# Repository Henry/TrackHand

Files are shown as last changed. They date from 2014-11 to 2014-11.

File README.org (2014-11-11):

#+TITLE: *DataHand DH200-6 with USB Micro-controller and Laser Trackball*
#+AUTHOR: nil
#+EMAIL: no-reply
#+OPTIONS: author:nil email:nil ^:{}
#+LaTeX_HEADER: \usepackage[parfill]{parskip}
#+STARTUP: hidestars odd

* Aim
  The initial aim of this project is to replace the archaic firmware in a
  DataHand DH200-6 keyboard with an ARM-based micro-controller and USB interface
  and use this as a test-platform for an integrated laser trackball using the
  ADNS-9800 LaserStream gaming sensor fitted closely below the finger cluster.
  The trackball is intended for finger control with the mouse buttons included
  in a special mode and mapped to the thumb-cluster keys.  The proposed layout
  of ball and switches is reminiscent of the excellent but obsolete Logitech
  TrackMan Marble FX trackball which I used for 15years:
  [[http://www.youtube.com/watch?v=k_sZMnmEOp4][Logitech TrackMan video]].

  Once the initial aim is fulfilled the trackball hardware and software could be
  fitted to the
  [[http://geekhack.org/index.php?topic=41422.msg827691#msg827691][DodoHand]] as
  an alternative to the proposed TrackPoint pointing device.  Details of this
  project may be found in the same thread:
  [[http://geekhack.org/index.php?topic=41422.msg1509793#msg1509793][TrackHand]]
  with some discussion concerning the suitability of the 2 1/4" trackball for
  the DodoHand.
* Images
  Here are the upgraded units with a trackball in the right-hand unit only,
  mouse buttons mapped to the right-hand thumb-cluster in function mode and
  current legends:
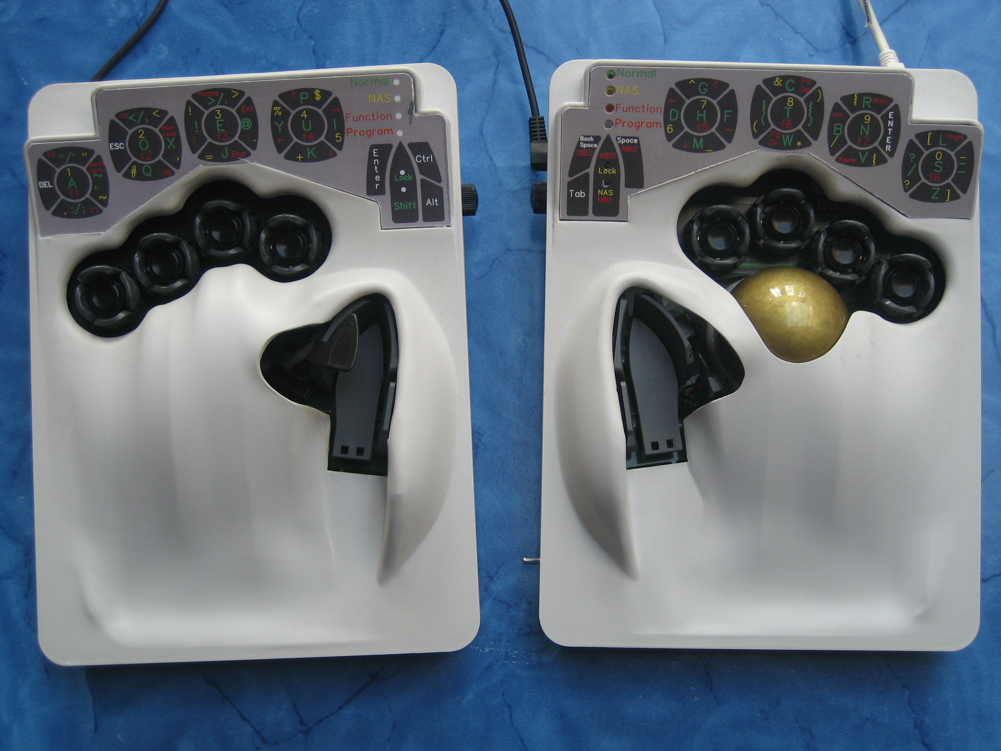
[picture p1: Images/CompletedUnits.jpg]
  
  Here is the inside of the right-hand unit showing the new micro-controller and
  trackball with the ADNS-9800 sensor:
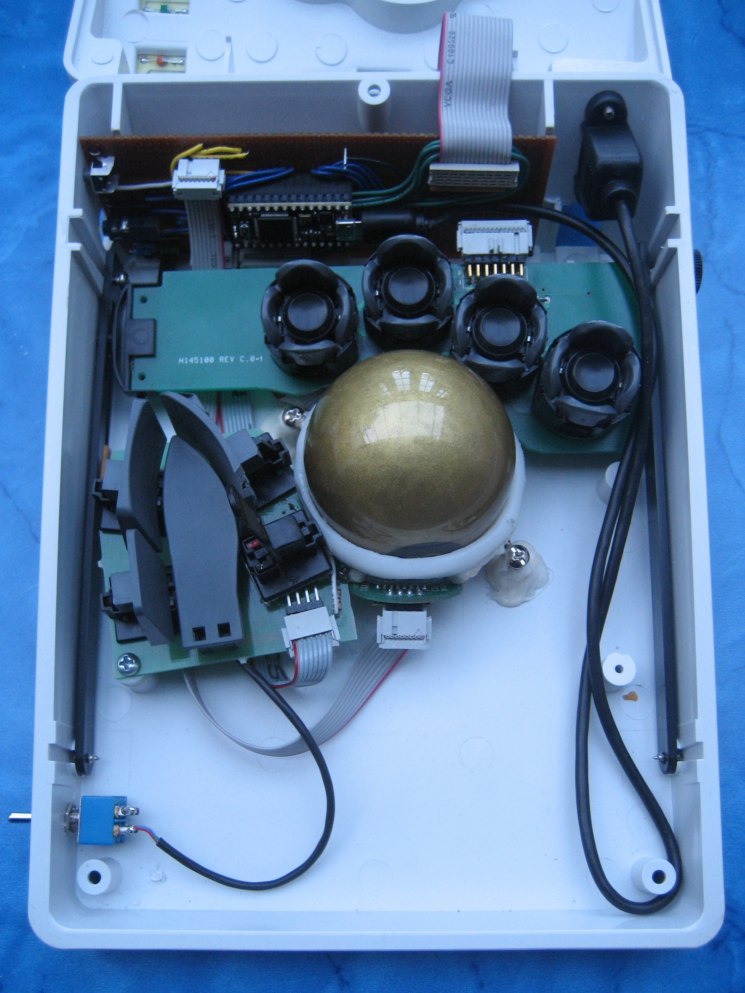
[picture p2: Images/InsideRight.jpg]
  
* Teensy 3 Software
  The [[https://www.pjrc.com/teensy/teensy31.html][Teensy-3.1]] micro-controller
  is used in this project.  Any of the Teensy
  boards could be used but I wanted to play around with this latest and most
  powerful offering from PJRC and the price is very reasonable.  The
  installation notes are really for my own reference but they may be useful to
  others.  I am developing software under OpenSuSE but all these tools are
  available for other GNU/Linux distributions.
*** Install AVR tools on OpenSuSE
    Open /firefox/ and follow instructions on
    + http://software.opensuse.org/package/cross-avr-gcc
    + Use the 1-click install of /CrossToolchain:avr/
    Or add the repository and use =zypper=
    + sudo zypper addrepo http://download.opensuse.org/repositories/CrossToolchain:/avr/openSUSE_13.1/
    + =zypper in cross-avr-gcc avr-libc cross-avr-binutils=
*** Enable serial (based on notes from PJRC)
    The udev rule file gives non-root users permission to use the Teensy device.
    Download [[http://www.pjrc.com/teensy/49-teensy.rules][49-teensy.rules]]
    + =sudo cp 49-teensy.rules /etc/udev/rules.d/=
    Add user to /uucp/ and /dialout/ groups
    + =uucp:x:14:<username>=
    + =dialout:x:16:<username>=
*** Avoid Teensyduino
    Teensyduino is the annoying Java interface to building and loading teensy
    applications.  This is the only method supported directly by PJRC on the
    Teensy-3.1.  However, other people are maintaining CLI support software for
    the Teensy-3.1 based on the applications released by PJRC for the Teensy-2.
*** Make (used instead of Teensyduino)
    Install the arduino libraries and make file for Teensy-3.x
    + =git clone= https://github.com/apmorton/teensy-template
    This repository started from the /teensy-template/ repository, so you do not
    need this step unless you want to write code for another project.

    To test simply
    + =make=
    + =make upload=
    + Press the button
*** CLI Loader (used instead of Teensyduino)
    Download the latest CLI app for teensy-3.1
    + =git clone= https://github.com/texane/teensy3.git
    + =cd teensy3/src/teensy_loader_cli=
    + =make=
    + Install somewhere in your =PATH= /eg/: =cp teensy_loader_cli ~/bin/linux=
*** Using GNU screen or cat to listen to serial messages
    On OpenSuSE the USB serial device =/dev/ttyACM0= is created following
    =Serial.begin()= and may be interrogated using =screen= or just plain old
    =cat=:
    + =screen /dev/ttyACM0=
    + =cat /dev/ttyACM0=
    Sometimes there is a problem with the connection and printing stops due to
    buffering.  To remedy this change the tty settings:
    + stty -F /dev/ttyACM0 9600 raw
*** I2C comms library
    This library is included: /libraries/i2c_t3/
    + http://forum.pjrc.com/threads/21680-New-I2C-library-for-Teensy3
    I2C is used to connect the right-hand unit to the left-hand MCP23018
    IO-expander.
***** Teensy-3 pins
      + SCL: pin 19 with 4k7 pull-up resistor
      + SDA: pin 18 with 4k7 pull-up resistor
      To connect two teensys connect SCL to SCL and SDA to SDA with the pull-up
      resistors.
*** Serial Peripheral Interface (SPI) library
    This library is included: /libraries/spi4teensy3/
    + https://github.com/xxxajk/spi4teensy3
*** Low-power library
    This is included: /libraries/LowPower_Teensy3/
    + [[https://github.com/duff2013/LowPower_Teensy3.git]]
*** MCP23018 library
    Interface to the MCP23018 IO-expander used to scan the optical switch matrix
    in the left-hand unit and send the data to the Teensy-3.1 micro-controller
    in the right-hand unit via the I2C connection.  This library is an
    incomplete but sufficient interface to the MCP23018 chip created for this
    project with reference to the
    [[http://ww1.microchip.com/downloads/en/DeviceDoc/22103a.pdf][MP23018
    datasheet]].
*** ADNS-9800 LaserStream Gaming Sensor library
    The ADNS-9800 LaserStream Gaming Sensor is used to scan the motion ball.
    The Kicklighter breakout board is used
    + https://www.kickstarter.com/projects/1034145369/high-speed-laser-optical-sensor
    + https://www.tindie.com/products/jkicklighter/adns-9800-optical-laser-sensor/

    Teensy interface for the ADNS-9800 used in this project is based on that
    provided by John Kicklighter and connects to the Teensy-3.1 via the SPI
    + https://github.com/mrjohnk/ADNS-9800.git
    + https://github.com/mrjohnk/Trackball2.git
    with updates for the Teensy-3.1 from
    + https://github.com/pepijndevos/Dwergmuis
    and is included: /libraries/TrackBall/
* The DataHand DH200-6
  The DataHand keyboard receiving this extreme makeover is a second-hand 1993
  DH200-6 is decent condition and basically working.  All the existing
  electronics are removed leaving just the thumb and finger switch clusters.
  The leds on the key map panel are also be reused.
*** Thumb Cluster
    The 8-pin IDC header on thumb-cluster has the following connections and
    proposed Teensy-3.1 pin allocation
    | Pin | Line           | Switches | Connections               | Teensy pin |
    |-----+----------------+----------+---------------------------+------------|
    |   1 | Vcc            |          |                           |            |
    |   2 | XD0 (column 0) | 1 3 5    |                           |         14 |
    |   3 | Row 0          | 1 2      | ->D1k->(D1)->D2k->R1->Vcc |          5 |
    |   4 | XD1 (column 1) | 2 4 6    |                           |         15 |
    |   5 | Row 1          | 3 4      | ->D3k->(D3)->D4k->R1->Vcc |          6 |
    |   6 | Row 2          | 6        | ->D3k->R1->Vcc            |          8 |
    |   7 | Row 3          | 5        | ->D5k->R1->Vcc            |          7 |
    |   8 | GND            | 1-6      |                           |            |
    + Connect 1 to Vcc
    + Connect 8 to GND
    + Connect columns 0 and 1 to INPUT pins each with a 4k7 pull-up to Vcc.
    + Set rows 0-3 to HIGH
    + Scan rows by setting each to LOW in turn
    + Read state of each column, LOW is on.
*** Finger Cluster
    The 14-pin IDC header on finger-cluster has the following connections and
    proposed Teensy-3.1 pin allocation
    | Pin | Line           |                               Teensy pin |
    |-----+----------------+------------------------------------------|
    |   1 | Vcc            |                                          |
    |   2 | XD0 (column 0) |                                       14 |
    |   3 | Row 4          |                                        1 |
    |   4 | XD1 (column 1) | 15 (now 16 but should be put back to 15) |
    |   5 | Row 5          |                                        0 |
    |   6 | Row 6          | 16 (now 15 but should be put back to 16) |
    |   7 | Row 7          |                                        3 |
    |   8 | Row 8          |                                       17 |
    |   9 | Row 9          |                                        2 |
    |  10 | Row 10         |                                       20 |
    |  11 | Row 11         |                                       23 |
    |  12 | Row 12         |                                       21 |
    |  13 | Row 13         |                                       22 |
    |  14 | GND            |                                          |
    |     |                |                                          |
    + Connect 1 to Vcc
    + Connect 14 to GND
    + Connect columns 0 and 1 to INPUT pins each with a 4k7 pull-up to Vcc.
      (NOTE: columns 0 and 1 are the same for finger and thumb clusters)
    + Set rows 4-14 to HIGH
    + Scan rows by setting each to LOW in turn
    + Read state of each column, LOW is on.
***** Thumb and Finger Switch Indices
      The following tables provide the column, row and combined indices for each
      of the thumb and finger switches:
      | Thumb Switch | Column/Row/index |
      |--------------+------------------|
      | Knuckle      | 0 0 0            |
      | Nail         | 1 0 1            |
      | Down         | 0 1 2            |
      | DOWN         | 1 1 3            |
      | Pad          | 0 3 6            |
      | Up           | 1 2 5            |

      | Finger | Down    | North   | South   | East    | West    |
      |--------+---------+---------+---------+---------+---------|
      |      1 | 0 5  10 | 1 4  9  | 0 7  14 | 1 5  11 | 0 4  8  |
      |      2 | 0 11 22 | 1 9  19 | 1 7  15 | 1 11 23 | 0 9  18 |
      |      3 | 0 12 24 | 1 13 27 | 0 10 20 | 1 12 25 | 0 13 26 |
      |      4 | 0 6  12 | 1 8  17 | 1 10 21 | 1 6  13 | 0 8  16 |
*** Trackball
    The ADNS-9800 LaserStream Gaming Sensor Kicklighter breakout board connects
    to the Teensy 3 on the SPI interface using 4 pins + 1 pin for interupt:
    | Pin | ADNS | Teensy | Description     | Teensy pin |
    |-----+------+--------+-----------------+------------|
    |   1 | MI   | MISO   | Data input      |         12 |
    |   2 | VI   | Vcc    | 3.3V            |            |
    |   3 | SC   | SCK    | Clock           |         13 |
    |   4 | AG   | GND    | Ground          |            |
    |   5 | MO   | MOSI   | Data output     |         11 |
    |   6 | DG   | GND    | Ground          |            |
    |   7 | SS   | SS     | Select device   |         10 |
    |   8 | MOT  | --     | Motion interupt |         9  |
*** LEDs
    The LEDs on the key map panel on the DataHand case are reused with the
    following pin allocation on the Teensy-3.1:
    | LED               | Teensy pin |
    |-------------------+------------|
    | Shift             |         24 |
    | Caps Lock         |         25 |
    | --                |         26 |
    | --                |         27 |
    | Cursor/mouse mode |         28 |
    | Function mode     |         29 |
    | NAS mode          |         30 |
    | Normal mode       |         31 |
    | --                |         32 |
    | --                |         33 |
    + Note: LOW is on
*** Teensy-3 pin allocation
    Pin requirements:
    | Purpose                               | #pins |
    |---------------------------------------+-------|
    | I2C (comms between teensys)           |     2 |
    | SPI (comms with trackball) + interupt |     5 |
    | Key matrix column inputs              |     2 |
    | Thumb row outputs                     |     4 |
    | Finger row outputs                    |    10 |
    | Mode and modifier indicator LEDs      |     6 |
    | Wake-up GPIO pin                      |     1 |
    |---------------------------------------+-------|
    | Total                                 |    30 |
* Trackball Installation
  To provide the best shape for the finger-driven trackball fitted is the curve
  of the finger-cluster I found that the standard 2 1/4" pool-ball to be the
  best compromise.  From a curvature point of view a slightly larger ball might
  be more comfortable but then it would need a higher case and would require
  further re-arrangement of the thumb switches.  Also the 2 1/4" pool-ball is
  the largest high-quality ball readily available.  Even with this size of ball
  a significant change needed to be made to the thumb-cluster to fit it in a
  suitable position, starting with the relocation of the "up" switch further in
  to allow aggressive trimming of the PCB and re-routing of cut tracks.  Slight
  trimming of the finger-cluster PCB was also required but this did not require
  the cutting and re-routing of any tracks.

  For convenient prototyping and testing I made the cup supporting the trackball
  by hand using [[http://www.polymorphplastic.co.uk/][Polymorph]] (known as
  Friendly Plastic in the US) by rolling a thick-ish sheet and molding around
  the ball with a thick rubber glove stretched over it to ensure the cup is
  slightly larger that the ball.  I created flattened regions on the cup for the
  fitting of the laser sensor and to fit it to the case using a belt-sander.
  The lugs to attach the laser sensor and fix the unit to the case are attached
  using hot-glue.  Three 2mm rubys support the ball and are fitted to the cup
  through 2mm drilled holes and pushed so they protrude using 2.5mm self-tapping
  screws.

  Initially I tried a cue-ball but the sensor could not detect the motion
  reliably if the ball moves fast.  This may be an issue with inaccurate
  positioning of the sensor.  I now use an
  [[http://www.aramithpoolballs.com/bbgold8.html][Aramith "Golden-8"]] ball with
  metallic finish which the sensor can follow more reliably.  This is the closes
  to the balls which Kensignton use but readily available and reasonably priced.
* Low-power sleep mode
  To save power, IR LEDs and in particular the laser sensor it is important to
  include a sleep mode.  Sleep functionality in the ARM-based Teensy 3.1 is
  completely different to the AVR-based Teensy 2 and a special library is
  needed:
  + [[https://github.com/duff2013/LowPower_Teensy3.git]]
  There are various modes of operation supported from reduced clock low-power
  modes to interruptable deep-sleep and hibernate modes.  The problem with the
  reduced clock modes is that the IR LEDs will still be powered although it
  would be possible to reduce the scanning frequency of the matrix.  The
  interruptable deep-sleep mode looks most appropriate but a pin would need to
  powered to interrupt the sleep which is not possible using the optical
  switched of the DataHand which would all be off during sleep.  The easiest
  solution is to provide a dedicated wake-up push-button switch attached to a
  dedicated wake-up pin on the Teensy 3.1.  Note that only a subset of the pins
  may be used for this purpose:
  |     | GPIO pin |
  |-----+----------|
  |  1. | PIN_2    |
  |  2. | PIN_4    |
  |  3. | PIN_6    |
  |  4. | PIN_7    |
  |  5. | PIN_9    |
  |  6. | PIN_10   |
  |  7. | PIN_11   |
  |  8. | PIN_13   |
  |  9. | PIN_16   |
  | 10. | PIN_21   |
  | 11. | PIN_22   |
  | 12. | PIN_26   |
  | 13. | PIN_30   |
  | 14. | PIN_33   |
  A push-button switch is attached to pin 33 for wake-up which works fine but it
  would be good to use the normal keys.  Given that the trackball laser is
  switched-off during sleep it is not possible to wake by moving the ball.  An
  alternative would be to use one of the rest modes of the ADNS9800 for laser
  saving and still support wake-up by moving the ball but this would require the
  SPI to be running, i.e. the Teensy 3.1 in sleep rather than deep-sleep mode
  which would be OK if it wired directly to the computer rather than wireless
  and battery powered.
* Compile and Upload
  The complete source code for the firmware may be found in the =TrackHand=
  directory and support libraries in the =libraries= directory.  The complete
  code may be compiled, linked and loaded using =make=:
  + Compile only: =make PROGRAM=TrackHand=
  + Compile and upload: =make PROGRAM=TrackHand load=
  The program defaults to =TrackHand= so
  + Compile only: =make=
  + Compile and upload: =make load=
  is sufficient.

  To initialize the configuration parameters stored in EEPROM it is necessary to
  compile and load with the =INITIALIZE=1= set on command line the first time
  the firmware is loaded:
  + Compile and upload: =make INITIALIZE=1 load=
  After initialization the standard firmware may be loaded which uses the
  current configuration stored in EEPROM:
  + Compile and upload: =make load=
* Dvorak Layout
  I have created a Dvorak-like layout based on the Kinesis and DataHand
  Professional II Dvorak layouts adjusted for programming convenience.
  To allow parentheses to be typed without shift they are included in the normal
  key-map directly with the shift being generated automatically.  Also to allow
  complete flexibility for shifted keys the shift and shift-lock keys enable a
  shift-mode rather than simply applying the shift-modifier.  While the
  locations of the normal characters is fairly obvious it is less clear where
  the symbols should be located and this is still in a state of flux.

  The CAD and PS files for the keyboard legends are in the =KeyboardLegends=
  directory.  Here are the current keyboard legends for the right-hand and
  left-hand units:
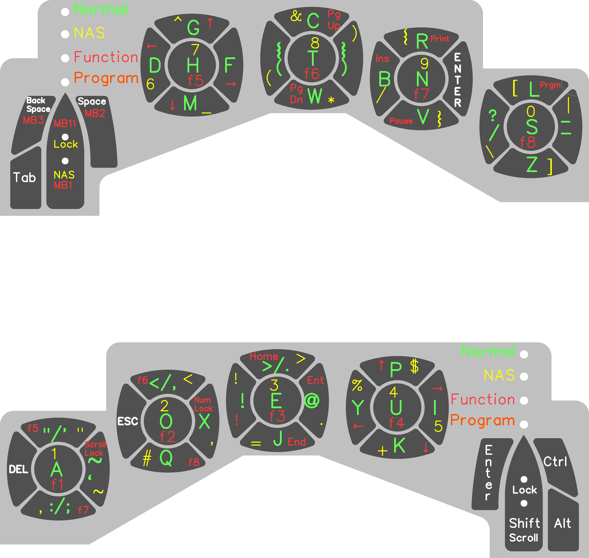
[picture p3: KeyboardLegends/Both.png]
  
*** Learning to Touch-type
    I am using [[http://klavaro.sourceforge.net/en/][klavaro]] to learn to touch-type on the TrackHand.  I can already
    touch-type on the Kinesis Advantage with the Dvorak layout and the I have
    created a layout for the TrackHand which is reasonably similar which has
    been helpful when learning the normal keys but the layout of the symbols is
    VERY different.  I set the keyboard to =USA dvorak= and found that the
    tutorials corresponded well to the layout of keys for both the alphabetic
    characters and reasonably well to the symbols.
* =thconf=: CLI TrackHand Configuration Utility
  =thconf= is a simple command-line utility provided to configure the
  TrackHand.  It is complied using the =Makefile= in the TrackHand directory and
  provides the following options:
  #+begin_example
  Usage: thconf [OPTION]...
  -h  --help               Print this usage information.
  -d  --dev <name>         Name of the serial device used to communicate with the TrackHand.
  -p  --print              Request that the TrackHand prints the current configuration.
  -r  --resolution <val>   Set the pointer motion resolution in increments of 50cpi in range 1-168.
  -s  --scroll <val>       Set the scroll divider to reduce the scroll speed.
  -t  --timeout <val>      Time of inactivity after which power saving is enabled.
  #+end_example

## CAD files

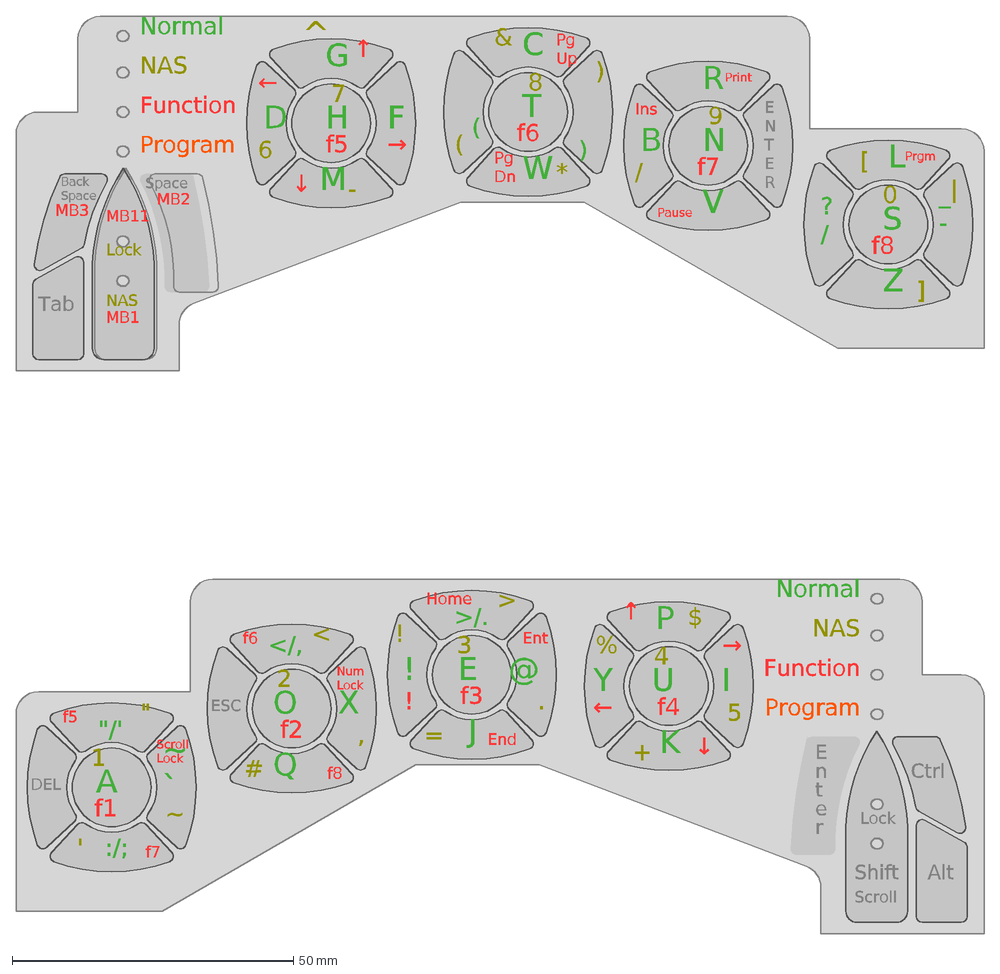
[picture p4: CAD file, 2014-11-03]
KeyboardLegends/Both.dxf
H
T
N
S
G
C
R
D
B
M
Z
V
W
↑
↓
→
←
A
E
U
Q
J
K
P
Y
X
:/;
</,
"/'
I
O
7
6
^
F
)
(
8
Pg Dn
/
9
E N T E R
? /
]
L
Pg Up
0
[
f1
DEL
~ `
2
3
4
5
ESC
1
~
!
@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

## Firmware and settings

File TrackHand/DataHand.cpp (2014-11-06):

/// Copyright 2014 Henry G. Weller
// -----------------------------------------------------------------------------
//  This file is part of
/// ---     TrackHand: DataHand with Laser TrackBall
// -----------------------------------------------------------------------------
//
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
// -----------------------------------------------------------------------------
/// Title: Main function
///  Description:
//    Constructs the KeyMatrix, TrackBall and PowerSave classes
//    and enters the matrix scan loop.
//    The trackball operates pointer movement on interrupt.
//    The trackball may also be used for scrolling selected by appropriate key.
// -----------------------------------------------------------------------------

#include "KeyMatrix.h"
#include "TrackBall.h"
#include "PowerSave.h"
#include "MCP23018.h"
#include "EEPROMParameters.h"

// -----------------------------------------------------------------------------

// Construct the keyboard matrix
// with the parameters stored in EEPROM starting at 0
KeyMatrix keyMatrix(0);

// Construct the trackball
// with the parameters stored in EEPROM starting immediately after the keyMatrix
TrackBall trackBall(keyMatrix.eepromEnd());

// Construct the power-saving mode for the keyboard and trackball
// with the parameters stored in EEPROM starting immediately after the trackBall
PowerSave powerSave(keyMatrix, trackBall, trackBall.eepromEnd());

int main(void)
{
    keyMatrix.begin();
    trackBall.begin();
    powerSave.begin();

    while (1)
    {
        // Put into power-save mode when keys are not pressed
        // or trackball not moved for some time
        powerSave
        (
            // Check for key presses
            keyMatrix.keysPressed()

            // Check for pointer motion and move or scroll
         || trackBall.moveOrScroll(!keyMatrix.scroll())
        );

        if (Serial.available())
        {
            uint8_t command = Serial.read();

            bool handled = false;

            handled |= keyMatrix.configure(command);
            handled |= trackBall.configure(command);
            handled |= powerSave.configure(command);

            if (!handled)
            {
                // Discard any buffered input
                usb_serial_flush_input();
                Serial.print("TrackHand: configuration command ");
                Serial.print(command);
                Serial.println(" failed");
            }
        }

        keyMatrix.pause();
    }

    return 0;
}


// -----------------------------------------------------------------------------

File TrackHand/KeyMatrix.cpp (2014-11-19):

/// Copyright 2014 Henry G. Weller
// -----------------------------------------------------------------------------
//  This file is part of
/// ---     TrackHand: DataHand with Laser TrackBall
// -----------------------------------------------------------------------------
//
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
// -----------------------------------------------------------------------------

#include "KeyMatrix.h"
#include "debug.h"

// -----------------------------------------------------------------------------

void KeyMatrix::set(const Mode& mode)
{
    if (currentMode_ != &mode)
    {
        currentMode_ = mode.set(currentMode_);
    }
}


void KeyMatrix::debugKey(const char* hand, const uint8_t row, const uint8_t col)
{
    debug("Pressed ");
    debug(hand);
    debug(": ");
    debug(col);
    debug(" ");
    debug(row);
    debug(" ");
    debugln(pressedKeys_[nPressed_]);
}


void KeyMatrix::scan()
{
    nPressed_ = 0;

    for (uint8_t ri=0; ri<nRows_; ri++)
    {
        uint8_t rhRow = rhRows_[ri];
        uint8_t lhRow = lhRows_[ri];

        digitalWriteFast(rhRow, LOW);
        leftHand_.writeBit(lhRow, LOW);

        delayMicroseconds(columnStabTime_);

        // Columns are ONLY on port A
        uint8_t lhColumns = leftHand_.readA();

        for (uint8_t ci=0; ci<nColumns_; ci++)
        {
            uint8_t rhColumn = rhColumns_[ci];
            uint8_t lhColumn = lhColumns_[ci];

            // Check the right-hand column
            if (digitalRead(rhColumn) == LOW)
            {
                if (nPressed_ < maxPressed_)
                {
                    pressedKeys_[nPressed_] = rhKey(ri, ci);
                    debugKey("RH", ri, ci);
                    nPressed_++;
                }
            }

            // Check the left-hand column
            if (!bitRead(lhColumns, lhColumn))
            {
                if (nPressed_ < maxPressed_)
                {
                    pressedKeys_[nPressed_] = lhKey(ri, ci);
                    debugKey("LH", ri, ci);
                    nPressed_++;
                }
            }
        }

        digitalWriteFast(rhRow, HIGH);
        leftHand_.writeBit(lhRow, HIGH);
    }
}


bool KeyMatrix::send()
{
    const Mode* mode = NULL;

    // The set of modifiers pressed
    uint8_t modifiers = 0;

    // Mouse buttons
    uint8_t mouseButtons[3] = {0, 0, 0};

    // Keep track of the mode key being held on
    // to avoid switching if the mode is locked
    bool modeKeyReleased = true;

    // Scan for mode and modifiers
    for (uint8_t keyi=0; keyi<nPressed_; keyi++)
    {
        // Lookup key-code for current mode
        KEYCODE_TYPE keyCode = currentMode_->keyCode(pressedKeys_[keyi]);

        if (modeKey(keyCode))
        {
            // Check if the mode key is being held on
            // and if so do not check for mode change
            if (pressedKeys_[keyi] == modeKeyPrev_)
            {
                modeKeyReleased = false;
                continue;
            }

            const Mode* newMode = NULL;

            switch(keyCode)
            {
                case modeKeyNorm_:
                    newMode = &normalMode_;
                    break;
                case modeKeyShift_:
                    newMode = &shiftMode_;
                    shiftMode_.unlock();
                    break;
                case modeKeyShiftLk_:
                    shiftMode_.lock();
                    break;
                case modeKeyNas_:
                    newMode = &nasMode_;
                    nasMode_.unlock();
                    break;
                case modeKeyNasLk_:
                    nasMode_.lock();
                    break;
                case modeKeyFn_:
                    newMode = &fnMode_;
                    break;
                case modeKeyMouse_:
                    newMode = &mouseMode_;
                    break;

                case modKeyShift_:
                    modifiers |= MODIFIERKEY_SHIFT;
                    break;
                case modKeyCtrl_:
                    modifiers |= MODIFIERKEY_CTRL;
                    break;
                case modKeyAlt_:
                    modifiers |= MODIFIERKEY_ALT;
                    break;

                case mouse1_:
                    mouseButtons[0] = 1;
                    break;
                case mouse1_1_:
                    // Double-click
                    mouseButtons[0] = 2;
                    break;
                case mouse2_:
                    mouseButtons[1] = 1;
                    break;
                case mouse3_:
                    mouseButtons[2] = 1;
                    break;
            }

            // If mode set store the corresponding pressed key
            if (newMode)
            {
                mode = newMode;
                modeKeyPrev_ = pressedKeys_[keyi];
            }
        }
    }

    // Only reset mode if the mode key has been released
    if (modeKeyReleased)
    {
        if (mode)
        {
            set(*mode);
        }
        else if (!currentMode_->locked())
        {
            // If the current mode is not locked reset to normal mode
            set(normalMode_);
        }

        // If no mode key pressed reset the previous mode key
        if (!mode)
        {
            modeKeyPrev_ = 0;
        }
    }

    uint8_t nSend = 0;
    KEYCODE_TYPE keyboardKeys[maxSend_] = {0, 0, 0, 0, 0, 0};
    bool unshiftedKeys = false;
    bool shiftedKeys = false;

    for (uint8_t keyi=0; keyi<nPressed_; keyi++)
    {
        // Lookup key-code for current mode
        KEYCODE_TYPE keyCode = currentMode_->keyCode(pressedKeys_[keyi]);

        // Mode and modifier keys already handled
        if (modeKey(keyCode)) continue;

        // Check for shifted keys
        if (shiftedKey(keyCode))
        {
            shiftedKeys = true;

            // Remove shift-bit
            keyCode &= ~shiftOffset_;
        }
        else
        {
            unshiftedKeys = true;
        }

        // USB supports maxSend_ (6) keys per send, ignore any more
        if (nSend >= maxSend_) break;

        // Add current key code to the set for sending
        keyboardKeys[nSend++] = keyCode;
    }

    // Set shift modifier if keys are shifted
    if (shiftedKeys)
    {
        // Return without sending if both shifted and unshifted keys are pressed
        if (unshiftedKeys)
        {
            return false;
        }

        modifiers |= MODIFIERKEY_SHIFT;
    }

    // Check that some keys pressed have changed and transfer to send buffer
    bool keysChanged = false;
    for (uint8_t keyi=0; keyi<maxSend_; keyi++)
    {
        keyboard_keys[keyi] = keyboardKeys[keyi];

        if (keyboardKeysPrev_[keyi] != keyboardKeys[keyi])
        {
            keysChanged = true;
        }

        keyboardKeysPrev_[keyi] = keyboardKeys[keyi];
    }
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

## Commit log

2014-10-26 Initial versions of the keyboard legends with the ~Dvorak layout Currently these are incomplete and will evolve further during testing.
    [Both.dxf, Right.dxf]
2014-10-26 Avoid warning messages due to the inconsistency between the KEYCODE_TYPE and KEY_? definitions in teensy3/keylayouts.h
2014-10-28 Further development of key-maps
    [Both.dxf]
2014-10-28 Corrected handling of modifiers
    [KeyMatrix.cpp]
2014-10-28 Updated legends
    [Both.dxf]
2014-10-28 Created template NAS key-map
    [Both.dxf, Right.dxf]
2014-10-28 Completed legends for thumb-clusters
    [Both.dxf]
2014-10-28 Change the shift key to set the modifier rather than mode when in function mode
    [Both.dxf]
2014-10-31 Improved NAS key-map
    [Both.dxf]
2014-11-02 Added \ and |
    [Both.dxf]
2014-11-03 Added support for scrolling using the trackball.
    Currently scrolling is selected in shift mode or with the shift
    modifier. This sets the y-motion of the trackball to scroll with a
    lower resolution than pointer movement; currently set to the lowest
    possible with the ADNS-9800 which is 50 cpi.
    If a lower resolution is required then the movement of the trackball
    will need to be accumulated in the TrackBall class so that the
    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
    [Both.dxf]
2014-11-04 Improved handling of trackball scrolling
    New parameter scrollDivider is provided to reduce the scroll speed
    relative to the pointer speed. Currently set to 50 which feels good.
    The resolution of the ADNS-9800 is no longer changed for scrolling.
2014-11-05 Started reworking the configuration support Added initial version of the CLI configuration tool
    [DataHand.cpp]
2014-11-06 Added support to print the current configuration parameters
2014-11-06 thconf now prints the data returned by the -p --print option
2014-11-07 Improved output of the -p --print option
2014-11-08 Add delay before resetting modifiers after screen wake to ensure they the reset is recognised
    [KeyMatrix.cpp]
2014-11-19 Change the screen wake-up method from sending the shift modifier to "wiggling" the pointer This avoids a "hanging" shift being cached affecting subsequent key-presses.
    [KeyMatrix.cpp, TrackBall.cpp]

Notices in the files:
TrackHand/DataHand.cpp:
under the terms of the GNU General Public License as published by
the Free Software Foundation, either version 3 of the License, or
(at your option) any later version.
